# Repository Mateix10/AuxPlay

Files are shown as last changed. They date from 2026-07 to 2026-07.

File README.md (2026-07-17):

# AuxPlay
A esp32 based AirPlay receiver for powered speakers. 

Note: This DOES NOT include a amplifier, please connect this device to powered speakers or a speaker amplifier.

Two speakers

Close up render

# Why?

I always wanted to play music wirelessly to my stereo. It was made in 2001 and it obviously does not have Bluetooth or AirPlay, so I decided to make a device that adds that functionality to it.

# Zine

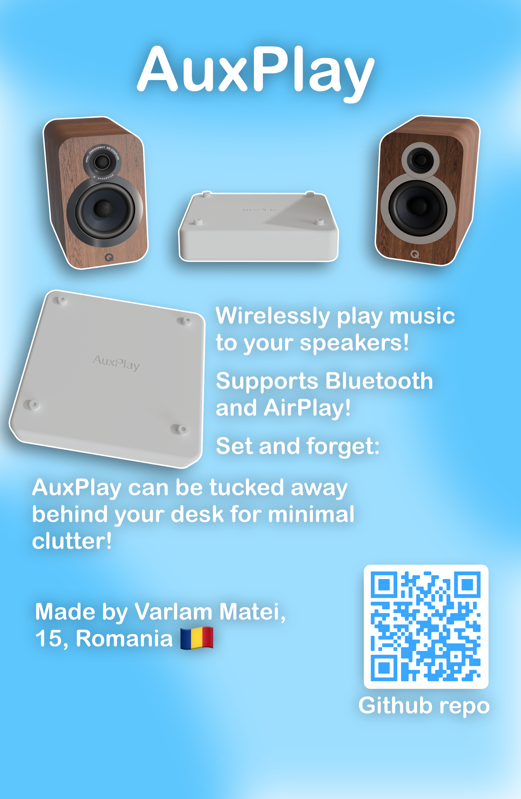
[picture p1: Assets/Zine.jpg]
Zine


# Schematic and PCB

For the "brains" I used a older esp32 module because the newer ones don't have classic bluetooth, required for Bluetooth A2DP, aka sound.

For the DAC, I used a PCM-5102 breakout board. Chose it for its sound quality. I used the breakout board for the extra filtering found on there and the ease of soldering it onto the PCB.

The PJ-320B 3.5mm headphone jack is connected through the PCB, using the pins on the DAC breakout board.

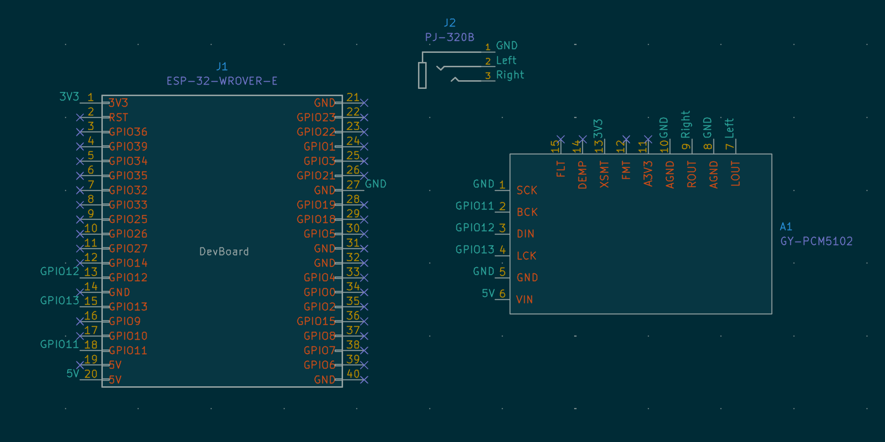
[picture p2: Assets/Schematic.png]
Schematic


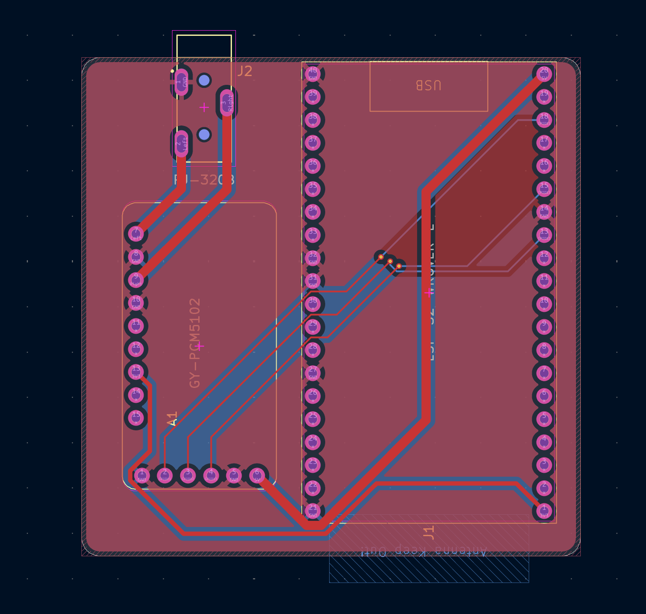
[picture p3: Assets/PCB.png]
PCB


# Case

For the case I used Fusion 360. The top part of the case along with the motherboard is screwed in with m2 screws. Preferably, the screws should be long (about 14mm) so it can reach the PCB along with the inserts at the bottom.

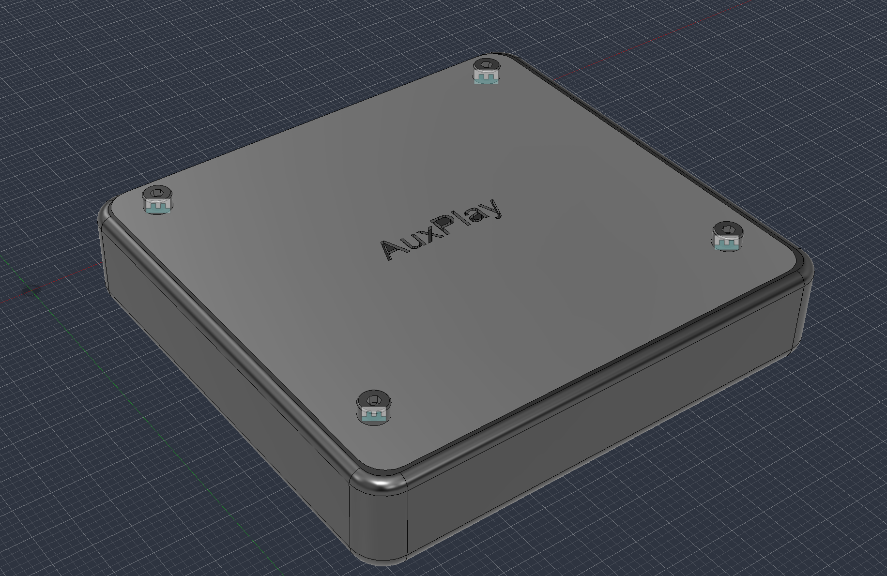
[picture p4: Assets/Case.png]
Case


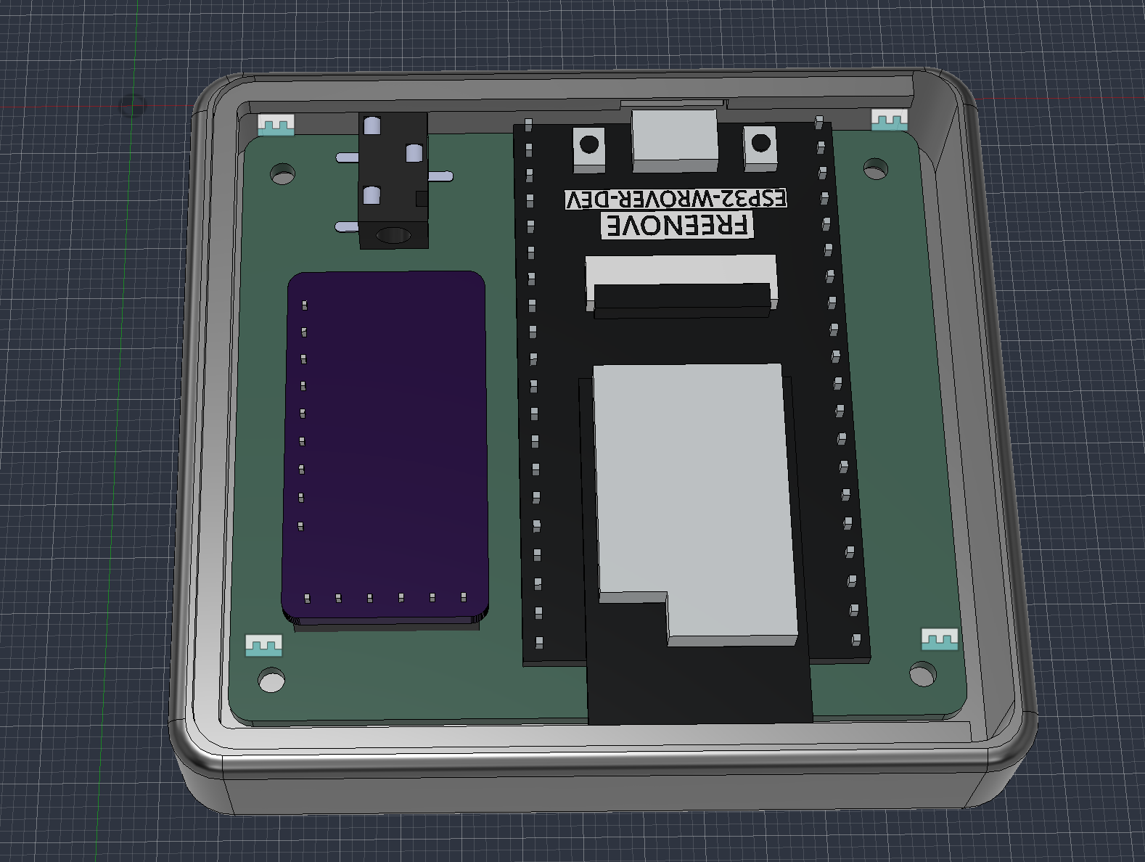
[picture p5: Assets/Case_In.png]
Inside of the case


# Firmware

For the firmware, I am using [airplay-esp32 by rbouteiller](https://github.com/rbouteiller/airplay-esp32).

# BOM

|Product|Count|Cost|Link|
|--|--|--|--|
|Esp32|1|$17.99|[Freenove Store](https://store.freenove.com/products/fnk0060)
|I2S PCM5102A DAC|1|$2.62|[Aliexpress](https://www.aliexpress.com/item/1005012477247485.html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)
|PJ-320B DIP Headphone Jack|1|$1.14|[Aliexpress](https://www.aliexpress.com/item/1005002436653862.html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)
|Screws|1|$7.43|[Aliexpress](https://www.aliexpress.com/item/4000038065691.html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)
|PCB|1|$2|[JLCPCB](https://jlcpcb.com/)
|Shipping + Tax||$36.65||
|TOTAL||67.83||

# Credits

[Kicad](https://www.kicad.org/) - Schematic and PCB design

[Fusion 360](https://www.autodesk.com/products/fusion-360/overview) - Designing the case

[sstojos's zynthian miniature project](https://github.com/sstojos/zynthian-miniature) - For the footprint and symbol of the PCM5102A DAC module that I used

[airplay-esp32 by rbouteiller](https://github.com/rbouteiller/airplay-esp32) - Firmware

[Hackclub Fallout](https://fallout.hackclub.com) - Founding

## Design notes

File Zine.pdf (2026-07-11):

# AuxPlay

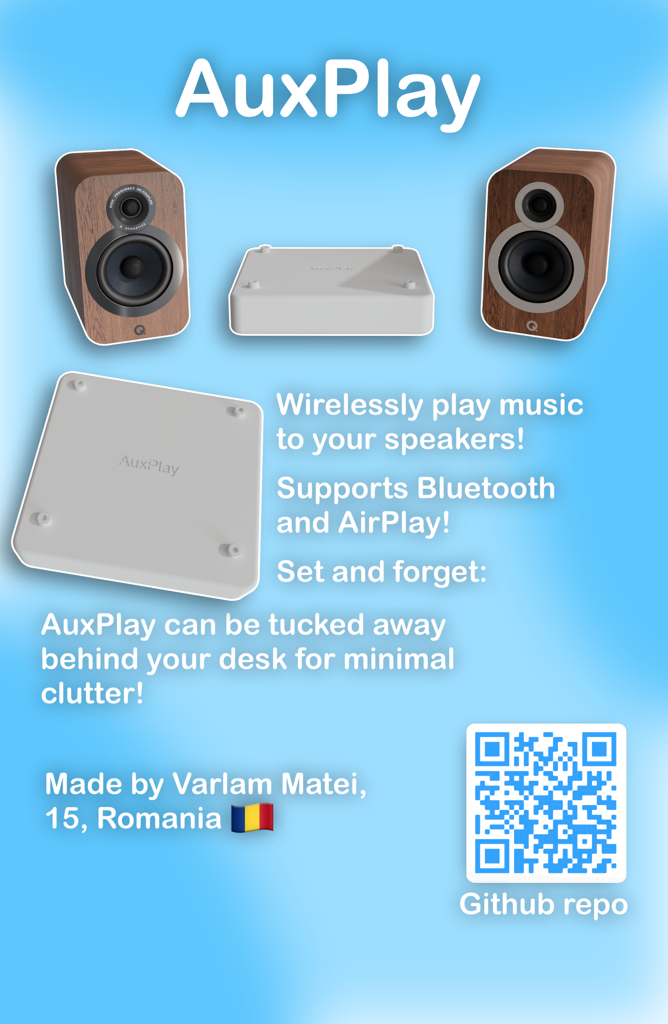
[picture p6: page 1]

Github repo

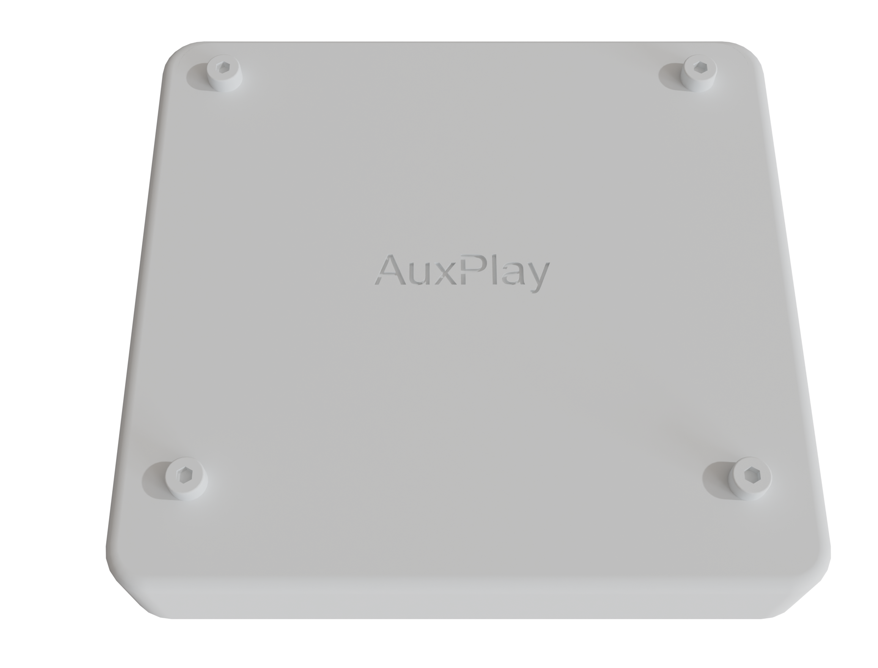
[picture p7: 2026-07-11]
3D/Renders/Device_Transparent4K.png

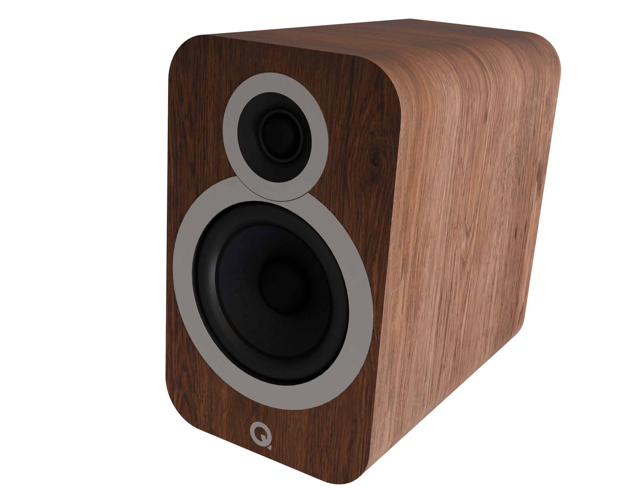
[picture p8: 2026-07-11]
3D/Renders/Speaker4K.png

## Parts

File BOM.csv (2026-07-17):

Product | Count | Cost | Link
Esp32 | 1 | $17.99 | https://store.freenove.com/products/fnk0060
I2S PCM5102A DAC | 1 | $2.62 | https://www.aliexpress.com/item/1005012477247485.html?curPageLogUid=5Cz8Hdx5unra
PJ-320B DIP Headphone Jack | 1 | $1.14 | https://www.aliexpress.com/item/1005002436653862.html?curPageLogUid=Cehayrqnawqp
Screws | 1 | $7.43 | https://www.aliexpress.com/item/4000038065691.html?curPageLogUid=T9XwEPeDqjrQ
PCB | 1 | $2 | https://jlcpcb.com/
Shipping + Tax |  | $36.65 | -
TOTAL |  | $67.83 | -

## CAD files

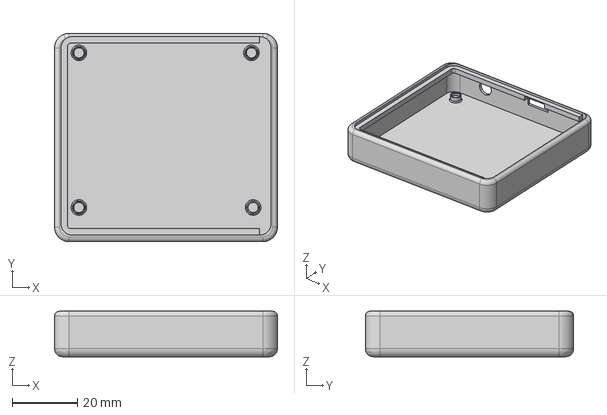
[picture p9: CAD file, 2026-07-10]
3D/Case_Bottom.step
68.5 x 64.0 x 14.0 mm

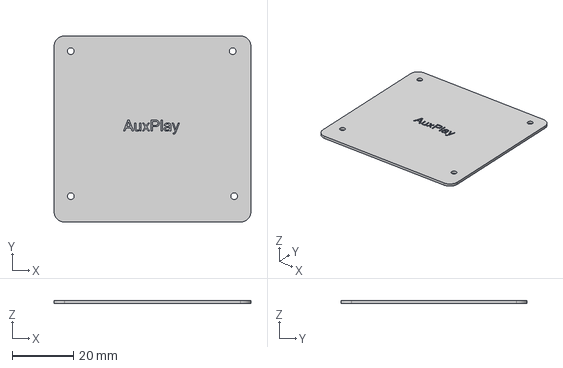
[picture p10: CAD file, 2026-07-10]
3D/Case_Top.step
64.5 x 61.0 x 1.00 mm

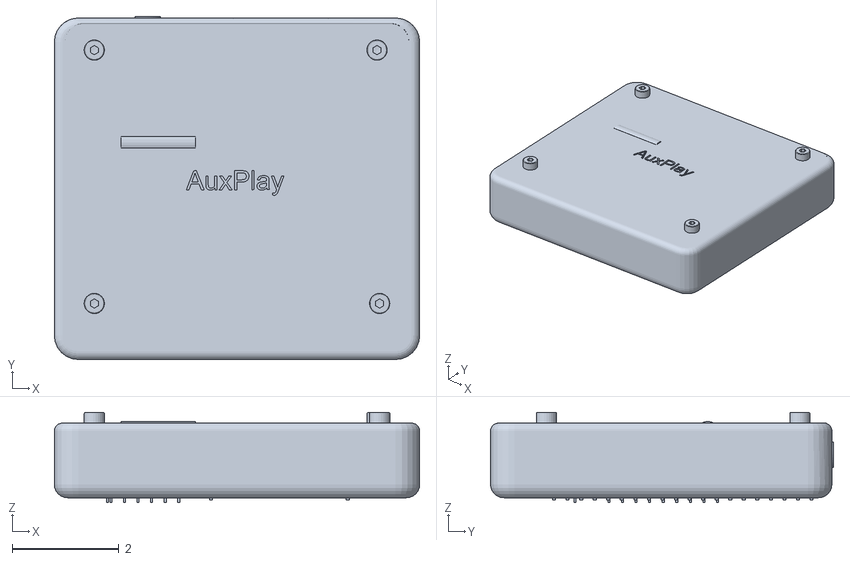
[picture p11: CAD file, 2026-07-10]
3D/AuxPlay.obj
6.85 x 6.43 x 1.69

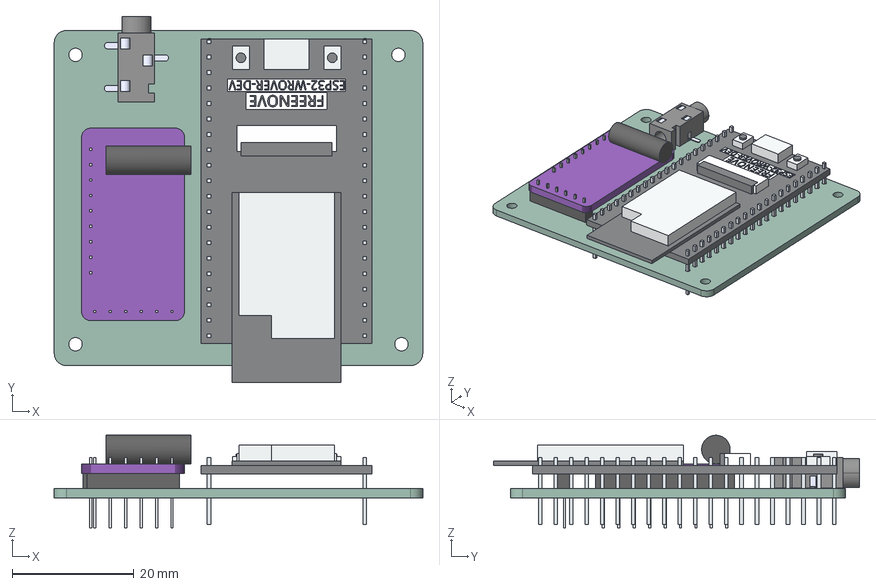
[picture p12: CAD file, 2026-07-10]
3D/PCB_final.step
60.5 x 60.1 x 15.2 mm
PJ-320B
Copy of FREENOVE ESP32-WROVER-DEV.f3d v0
AuxPlay_PCB

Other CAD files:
3D/AuxPlay.f3z
3D/Blender/assets/materials/black-plastic_5d077501-2739-44eb-8ed7-a99897d95238/black-plastic_2K_d53818b9-7dfc-4b44-ac51-068fa59820db.blend
3D/Blender/assets/materials/grained-white-pl_17a0bc37-f0d6-4a35-866c-b48b3f188255/grained-white-plastic_1K_b8d2857e-8975-4048-9c4f-11b8b3c6eb07.blend
3D/Blender/assets/models/m-audio-av-40-ac_082ea130-b22f-4aeb-9e50-27ae8fe45499/m-audio-av-40-active-speakers_2K_95e85c8e-dce5-463a-ba42-30adff2b013e.blend
3D/Case_Bottom.stl
3D/Case_Top.stl

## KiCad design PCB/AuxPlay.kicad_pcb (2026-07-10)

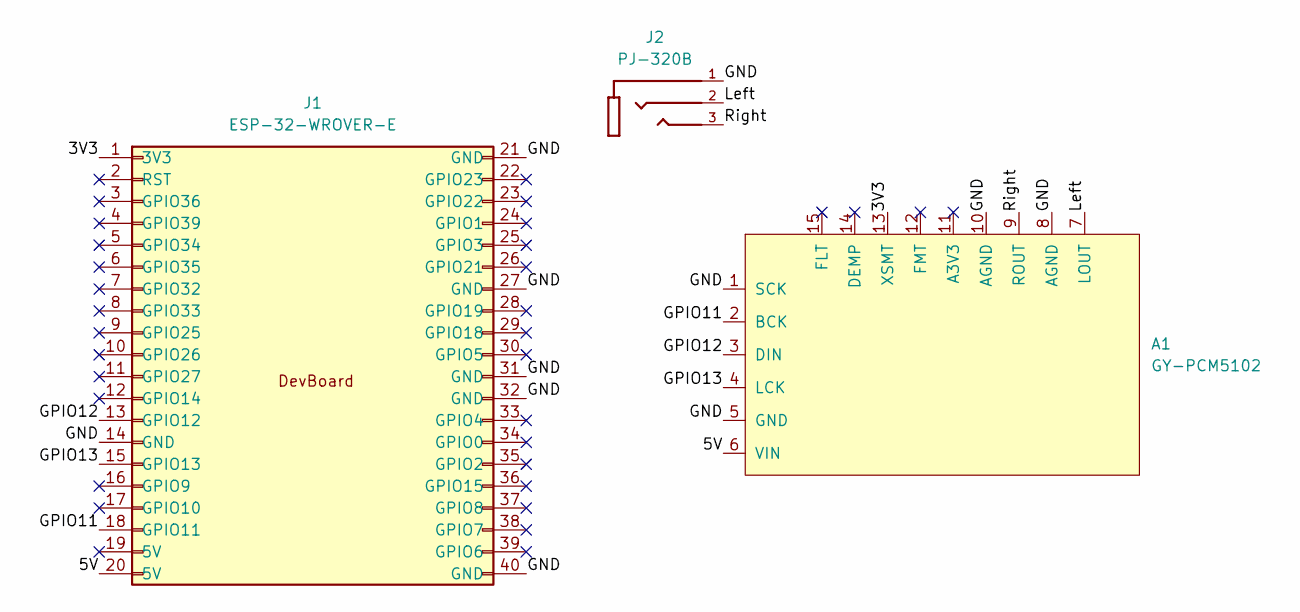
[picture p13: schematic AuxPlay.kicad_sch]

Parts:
A1: GY-PCM5102
J1: ESP-32-WROVER-E; Freenove_ESP32-CAM
J2: PJ-320B; BOOMELE_PJ-320B

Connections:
/3V3: A1.13 (XSMT), J1.1 (3V3)
/5V: A1.6 (VIN), J1.20 (5V)
/GND: A1.1 (SCK), A1.5 (GND), A1.8 (AGND), A1.10 (AGND), J1.14 (GND), J1.21 (GND), J1.27 (GND), J1.31 (GND), J1.32 (GND), J1.40 (GND), J2.1
/GPIO11: A1.2 (BCK), J1.18 (GPIO11)
/GPIO12: A1.3 (DIN), J1.13 (GPIO12)
/GPIO13: A1.4 (LCK), J1.15 (GPIO13)
/Left: A1.7 (LOUT), J2.2
/Right: A1.9 (ROUT), J2.3

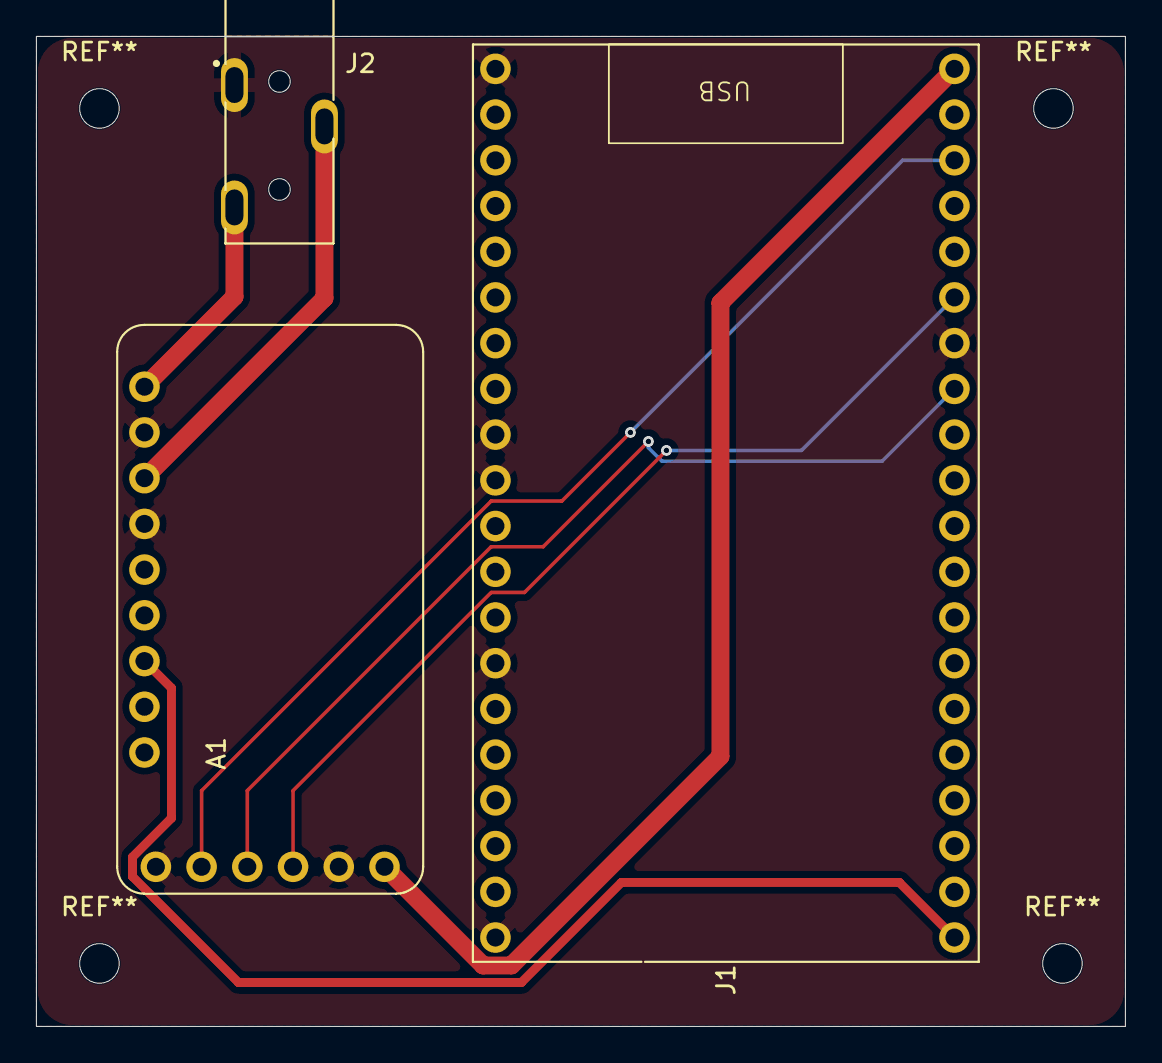
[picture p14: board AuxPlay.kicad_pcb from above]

Board: 2 copper layers, 60.5 x 55.0 mm, 3 parts (0 on the bottom side), 8 nets.

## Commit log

2026-07-10 Update README
    Updated README with additional details about the project, including schematic, PCB, case design, BOM, and credits.
2026-07-10 Add stuff
    [AuxPlay-B_Cu.gbl, AuxPlay-B_Mask.gbs, AuxPlay-B_Paste.gbp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]
2026-07-11 Add zine
    [PCB.step]
2026-07-11 Add BOM
    [BOM.csv]
2026-07-11 Fix BOM
    [BOM.csv]
2026-07-17 Add more info about schematic
